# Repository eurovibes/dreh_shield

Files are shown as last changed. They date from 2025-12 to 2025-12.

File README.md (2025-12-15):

<!-- SPDX-FileCopyrightText: 2025 Benedikt Spranger <b.spranger@linutronix.de> -->
<!-- SPDX-License-Identifier: CERN-OHL-S-2.0 -->




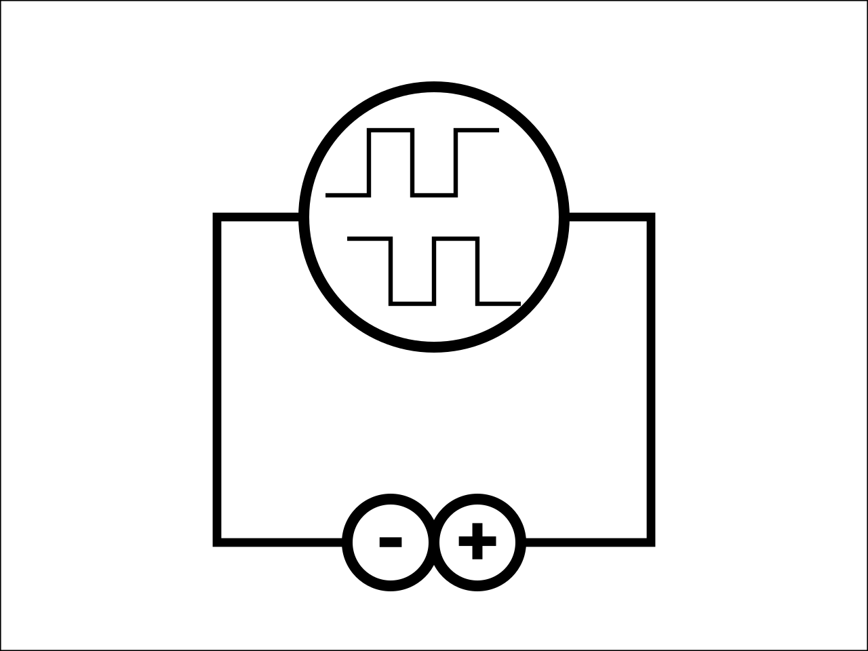
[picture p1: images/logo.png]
dreh_shield logo


# dreh_shield - An Arduino Uno R3 rotary encoder input shield

dreh_shield is an Arduino Uno R3 rotary encoder input shield for two A/B
rotary encoder. It is developed to act as a companion shield to the dc_shield
(https://github.com/eurovibes/dc_shield).

## License rules

dreh_shield is provided under the terms of the CERN-OHL-S license version 2 as
provided in the LICENSES/CERN-OHL-S-2.0 file.

Instead of adding license boilerplates to the individual files, dreh_shield uses
SPDX license identifiers, which are machine parseable and considered legaly
equivalent.

The SPDX license identifier in dreh_shield shall be added at the first possible
line in a file which can contain a comment. This is normally the first line
except for scripts. Scripts require the #!PATH_TO_INTERPRETER tag in the
first line; place the SPDX identifier into the second line.

The SPDX license identifier is added in form of a comment.

## Copyright and License

Copyright Benedikt Spranger 2021.
This source describes Open Hardware and is licensed under the CERNOHL-S v2.
You may redistribute and modify this source and make products using it
under the terms of the CERN-OHL-S v2
(https://ohwr.org/cern_ohl_s_v2.txt ).
This source is distributed WITHOUT ANY EXPRESS OR IMPLIED
WARRANTY, INCLUDING OF MERCHANTABILITY, SATISFACTORY
QUALITY AND FITNESS FOR A PARTICULAR PURPOSE. Please see
the CERN-OHL-S v2 for applicable conditions.
Source location: https://github.com/eurovibes/dreh_shield
As per CERN-OHL-S v2 section 4, should You produce hardware based
on this source, You must where practicable maintain the Source Location
visible on the external case of the dreh_shield or other products you make
using this source.

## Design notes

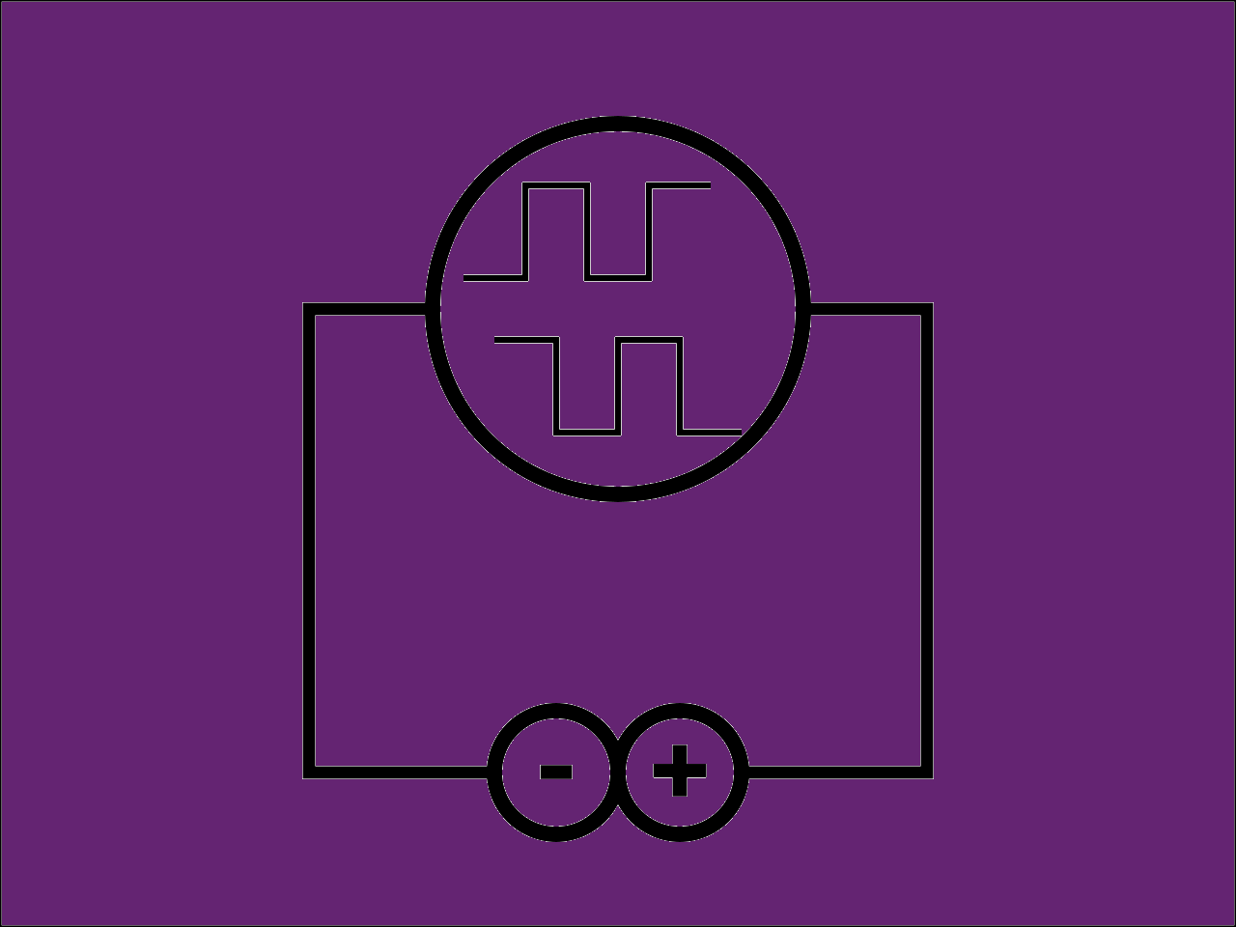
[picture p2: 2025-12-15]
images/dreh_shield_media.png

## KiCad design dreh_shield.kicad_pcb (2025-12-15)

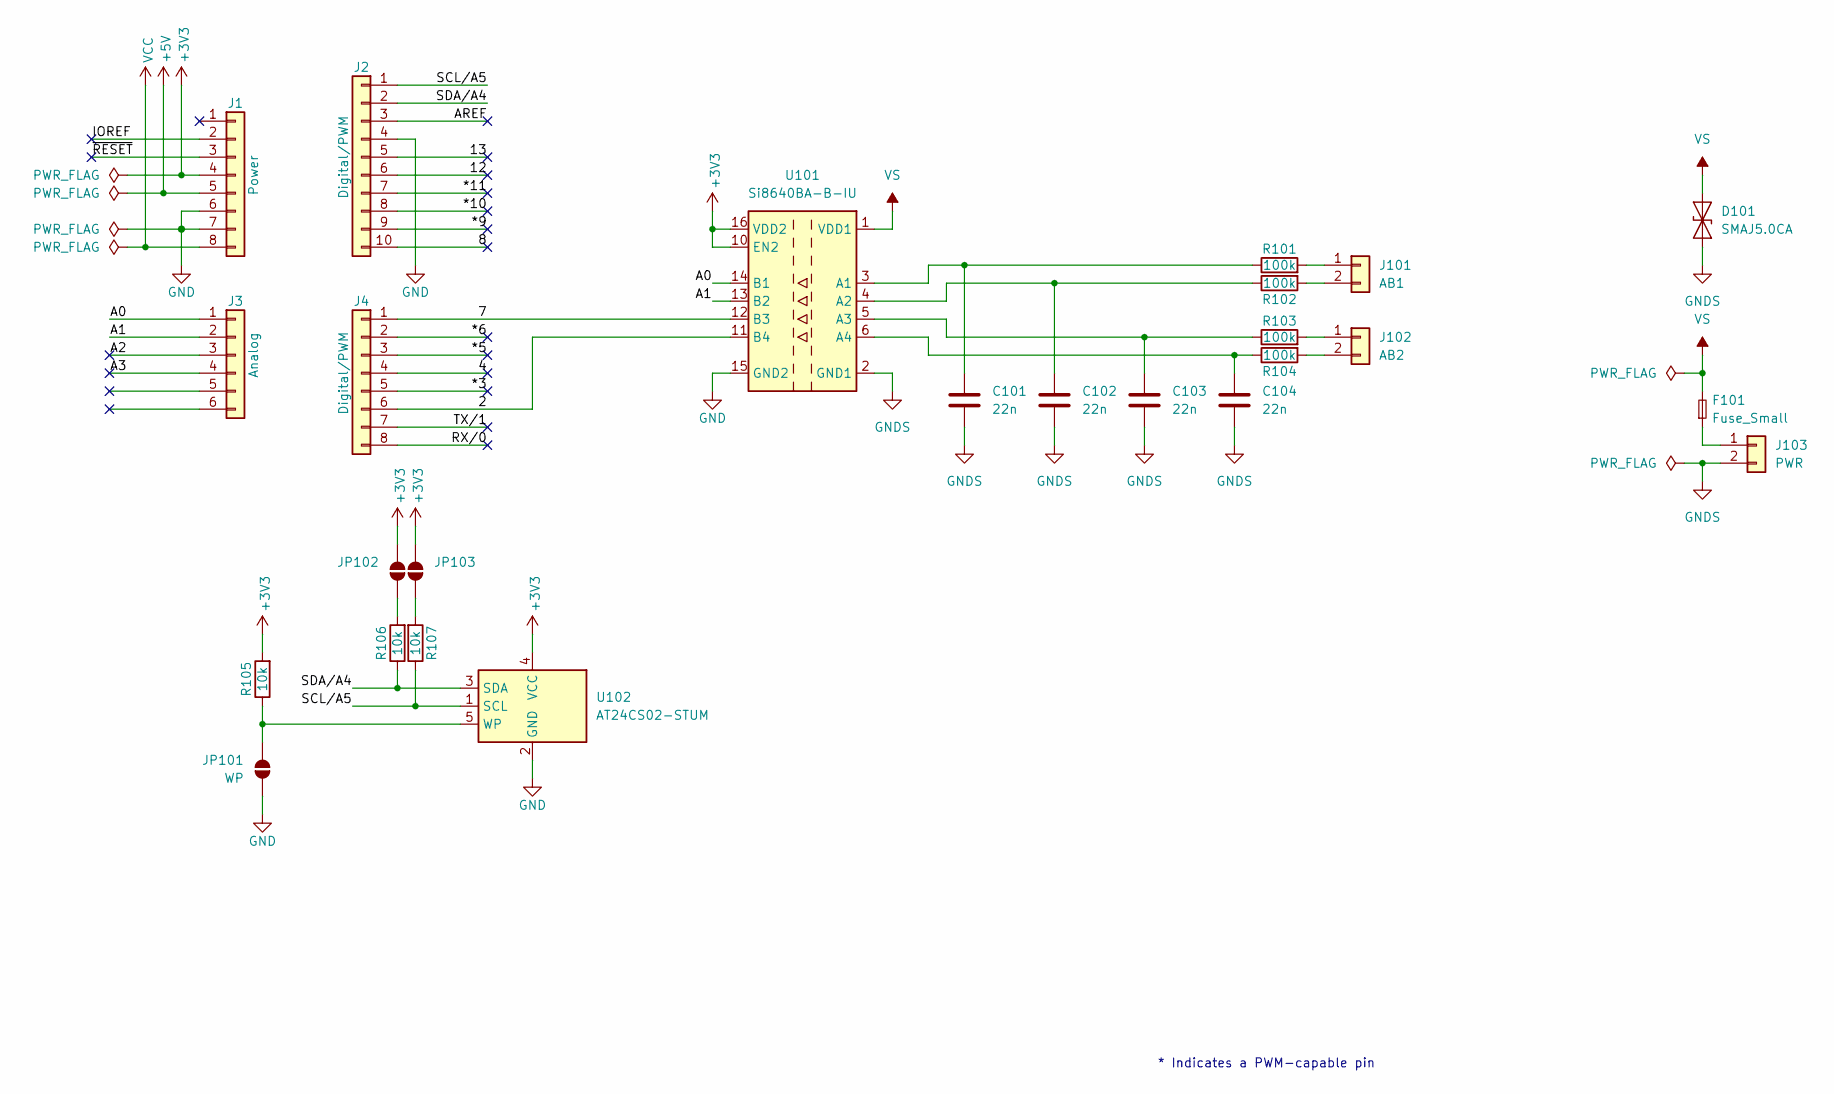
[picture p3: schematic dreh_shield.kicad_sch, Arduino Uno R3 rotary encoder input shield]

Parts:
C101, C102, C103, C104: 22n; C_0402_1005Metric; lcsc# C1532
D101: SMAJ5.0CA; D_SMA; lcsc# C908809
F101: Fuse_Small; Fuse_1206_3216Metric; lcsc# C70065
J1: Power; PinSocket_1x08_P2.54mm_Vertical; digikey# SAM9303-ND
J2: Digital/PWM; PinSocket_1x10_P2.54mm_Vertical; digikey# SAM15577-ND
J3: Analog; PinSocket_1x06_P2.54mm_Vertical; digikey# SAM9298-ND
J4: Digital/PWM; PinSocket_1x08_P2.54mm_Vertical; digikey# SAM9303-ND
J101: AB1; TerminalBlock_WAGO_236-402_1x02_P5.00mm_45Degree; digikey# 2946-236-402-ND
J102: AB2; TerminalBlock_WAGO_236-402_1x02_P5.00mm_45Degree; digikey# 2946-236-402-ND
J103: PWR; TerminalBlock_WAGO_236-402_1x02_P5.00mm_45Degree; digikey# 2946-236-402-ND
JP101: WP; SolderJumper-2_P1.3mm_Open_Pad1.0x1.5mm
JP102, JP103: SolderJumper-2_P1.3mm_Open_Pad1.0x1.5mm
R101, R102, R103, R104: 100k; R_0402_1005Metric; lcsc# C25741
R105, R106, R107: 10k; R_0402_1005Metric; lcsc# C25744
U101: Si8640BA-B-IU; QSOP-16_3.9x4.9mm_P0.635mm; lcsc# C52145203
U102: AT24CS02-STUM; SOT-23-5; lcsc# C5125083

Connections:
+3V3: J1.4, JP102.2 (B), JP103.2 (B), R105.2, U101.10 (EN2), U101.16 (VDD2), U102.4 (VCC)
+5V: J1.5
/2: J4.6, U101.11 (B4)
/4: J4.4
/7: J4.1, U101.12 (B3)
/8: J2.10
/12: J2.6
/13: J2.5
/*3: J4.5
/*5: J4.3
/*6: J4.2
/*9: J2.9
/*10: J2.8
/*11: J2.7
/A0: J3.1, U101.14 (B1)
/A1: J3.2, U101.13 (B2)
/A2: J3.3
/A3: J3.4
/AREF: J2.3
/IOREF: J1.2
/RX/0: J4.8
/SCL/A5: J2.1, R107.1, U102.1 (SCL)
/SDA/A4: J2.2, R106.1, U102.3 (SDA)
/TX/1: J4.7
/~RESET: J1.3
GND: J1.6, J1.7, J2.4, JP101.1 (A), U101.9 (GND2), U101.15 (GND2), U102.2 (GND)
GNDS: C101.2, C102.2, C103.2, C104.2, D101.1 (A1), J103.2, U101.2 (GND1), U101.8 (GND1)
unnamed: J101.1, R101.2
unnamed: J101.2, R102.2
unnamed: J102.1, R103.2
unnamed: J102.2, R104.2
unnamed: F101.1, J103.1
unnamed: JP101.2 (B), R105.1, U102.5 (WP)
unnamed: JP102.1 (A), R106.2
unnamed: JP103.1 (A), R107.2
unnamed: C101.1, R101.1, U101.3 (A1)
unnamed: C102.1, R102.1, U101.4 (A2)
unnamed: C103.1, R103.1, U101.5 (A3)
unnamed: C104.1, R104.1, U101.6 (A4)
VCC: J1.8
VS: D101.2 (A2), F101.2, U101.1 (VDD1)

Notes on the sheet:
* Indicates a PWM-capable pin

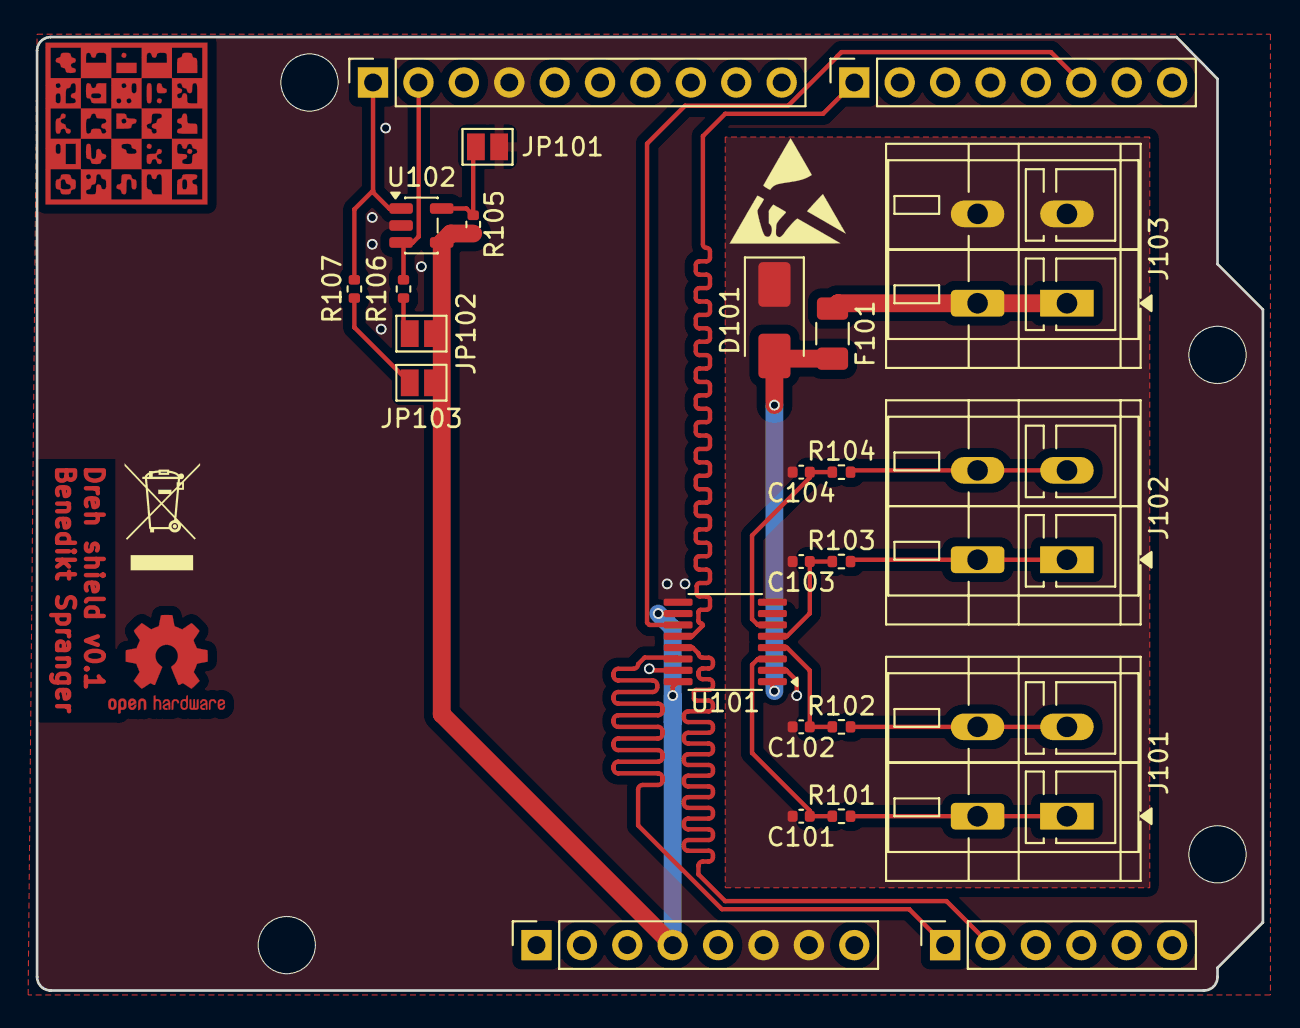
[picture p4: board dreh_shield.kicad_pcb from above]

Board: 2 copper layers, 68.6 x 53.3 mm, 29 parts (0 on the bottom side), 22 nets.

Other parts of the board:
MH1, MH2, MH3, MH4: MountingHole_3.2mm

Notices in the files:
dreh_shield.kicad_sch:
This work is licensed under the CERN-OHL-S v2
